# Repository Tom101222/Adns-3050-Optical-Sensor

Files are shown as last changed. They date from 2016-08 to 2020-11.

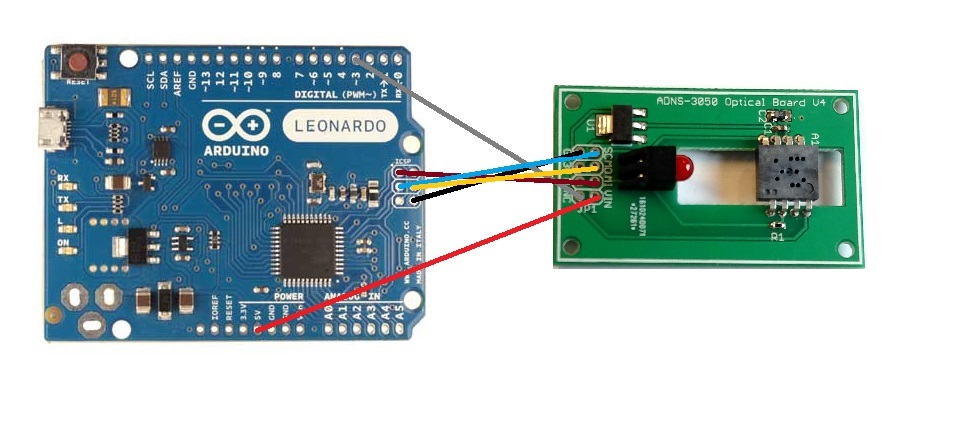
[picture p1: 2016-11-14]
Documentation/Wiring_Diagram.jpg

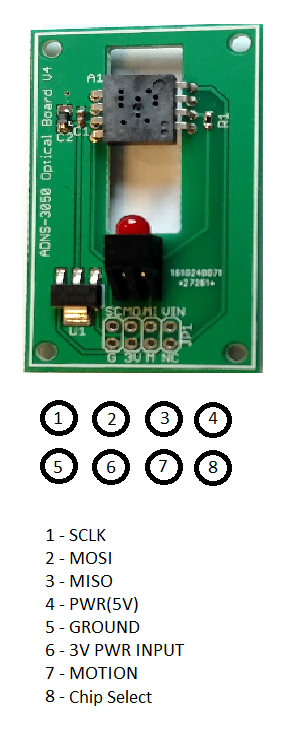
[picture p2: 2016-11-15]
Documentation/pinout.png

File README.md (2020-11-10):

# Adns-3050-Optical-Sensor
Library and Eagle cad files for the Adns-3050 Sensor

Boards are now avaible for purchase on tindie! https://www.tindie.com/products/tom10122/adns-3050-optical-sensor-board/

Overview

The ADNS 3050 is an entry level gaming sensor with up to 2000cpi resolution. It uses 6 wires to communicate via SPI(including Power) and can be used to create your own computer mouse in addition to other uses in robotics. 

Setup

Wiring
The pins used in the program are defined at the top of the header file.

MOSI -- MOSI, 

MISO -- MISO, 

SCLK -- SCLK, 

NCS -- 3 (any pin you want)

Software

A method has been provided to automate the setup of the sensor. It does not require as much setup as the adns-9800 laser based sensor. The default setup method (startup) uses all the default configuration options for the sensor but they can be changed easily. All configuration is done by writing to the correct registers on the sensor, a quick look over the datasheet should help anyone looking to change some settings, the write method can be used to write to the settings to the registers.  

Using to obtain postion

Once the startup method has been run it is easy to obtain the position of the sensor, just use getx() and gety() consecutively, it is important that there are no read operations between the two otherwise the data will be corrupted or changed.  

Sensor Operation

The ADNS 3050 is essentially a small camera. It takes consecutive photos and the DSP mathematically determines the amount of movement between pictures. The data is then stored in the DELTA_X and DELTA_Y registers (0X03 and 0X04 respectively) Once the the registers are read they are re-written with new data.

Setting the Resolution 

Resolution is determined by the value of bits 4-2 in the MOUSE_CNTRL register (0x0d). By default this is set to 1000 cpi. To change the resolution just write to the register with the corresponding value . For example, to set the resolution to 2000 cpi  just use:

Write(0x0d,B11000);

This sets bits 4-2 to 110 and bits 1 and 0 to 0 (needed for operation).  110 corresponds with the value found on page 29 of the datasheet for a resolution of 2000 

Lift off detection 

The sensor will stop tracking if the SQUAL is too low (usually when the sensor is too far off the ground). Sometimes when the sensor is placed back down it will not wake up. To mitigate/disable liftoff detection you can set the SQUAL_Threshold to 0 in the MISC_Settings register.The following code does just that:

Write(0x25,B0000001);

This should be run during setup.

Any questions or comments feel free to email me at twigg1012@gmail.com

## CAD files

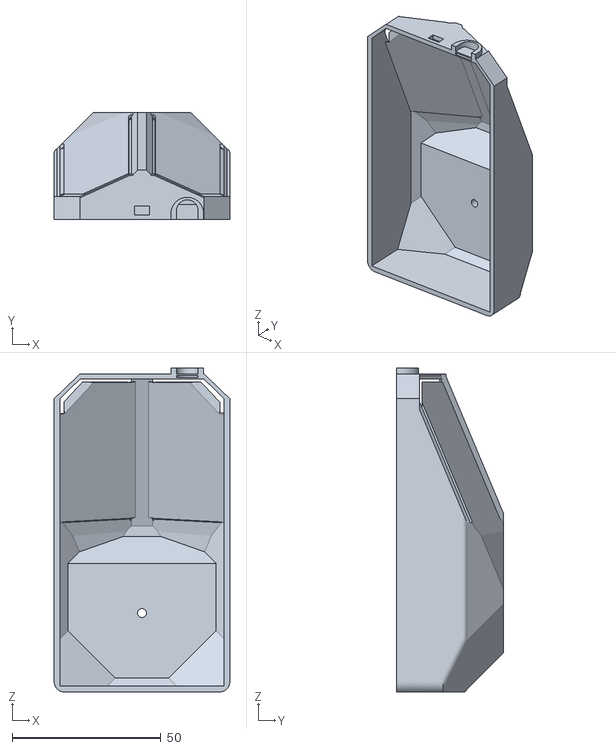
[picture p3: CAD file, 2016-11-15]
Hardware/3D Models/Mouse_Shell.stl
59.0 x 36.0 x 108.8

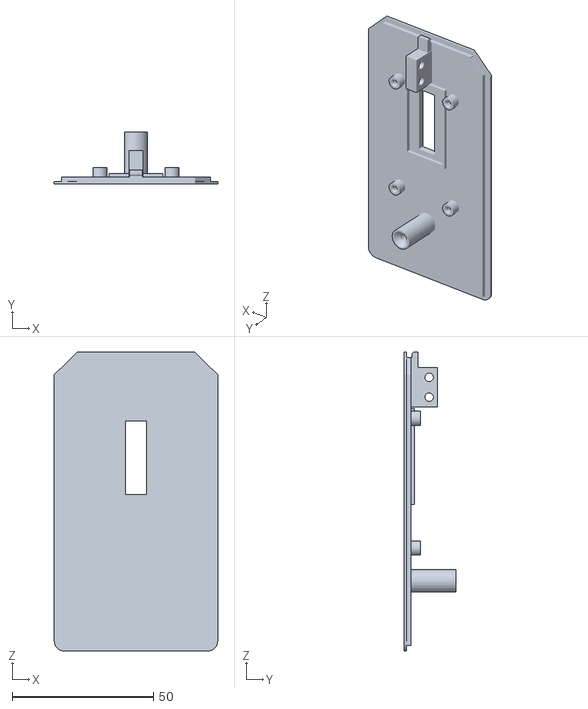
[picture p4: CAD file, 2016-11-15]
Hardware/3D Models/baseplate.stl
58.0 x 18.4 x 106.0

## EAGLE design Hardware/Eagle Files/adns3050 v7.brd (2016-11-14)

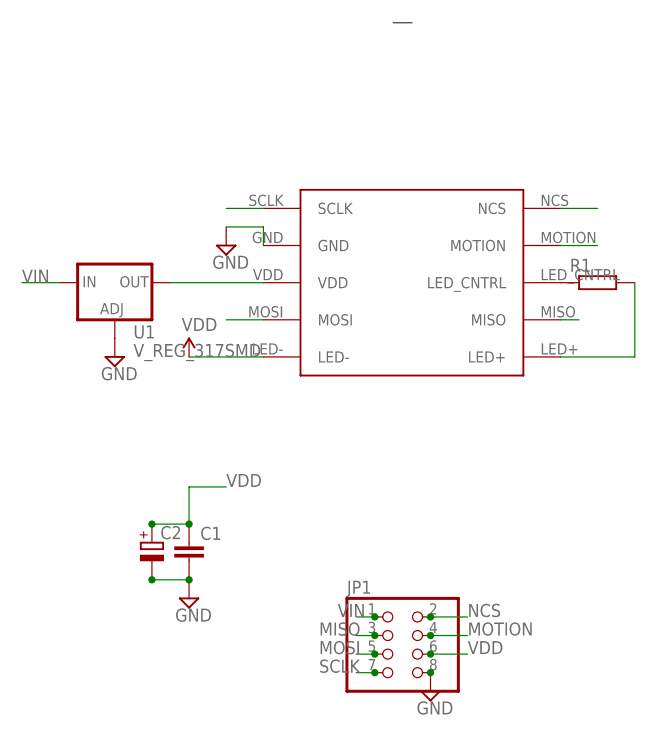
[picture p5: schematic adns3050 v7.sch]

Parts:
C1: CC0603; C0603
C2: CPOL-EUR/2012-12R; R/2012-12R
JP1: PINHD-2X4; 2X04
R1: RR0603; R0603
U1: V_REG_317SMD; SOT223
U$1: 3050; ADNS3

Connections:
GND: C1.2, C2.-, JP1.8, U1.1 (ADJ), U$1.GND
MISO: JP1.3, U$1.MISO
MOSI: JP1.5, U$1.MOSI
MOTION: JP1.4, U$1.MOTION
unnamed: R1.1, U$1.LED_CNTRL
unnamed: R1.2, U$1.LED+
NCS: JP1.2, U$1.NCS
SCLK: JP1.7, U$1.SCLK
VDD: C1.1, C2.+, JP1.6, U1.2 (OUT), U$1.LED-, U$1.VDD
VIN: JP1.1, U1.3 (IN)

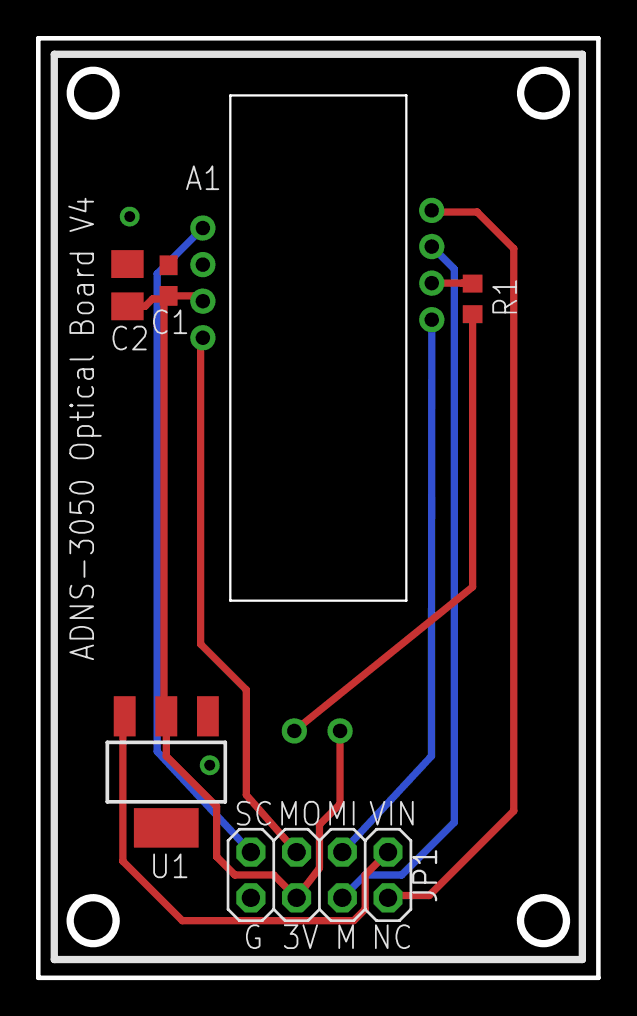
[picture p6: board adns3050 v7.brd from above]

Board: 2 copper layers, 31.1 x 52.2 mm, 6 parts (0 on the bottom side), 10 nets.

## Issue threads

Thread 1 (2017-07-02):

working with Teensy

robotpapier, 2017-07-02:
Hi,
is it working with Teensy 3.2?

Tom101222, 2017-07-02:
Hi, It will work with any device that can communicate over SPI, you just
need to change the pins used in the header file to match those on the
teensy ( MISO, MOSI, SCK, ECT)
Thanks.

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

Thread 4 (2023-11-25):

Low power (wireless) and rest mode

petanque, 2023-11-25:
Hi, thank you for sharing this.
I am trying to make a wireless version and it works with lower power but when I start rest mode I get no output on the serial port and it does not use less power as expected.

In your startup I added this:

//enable low power mode
Write(NAV_CTRL2, 0x00);
Write(FRAME_IDLE, 0x26);
Write(PREFLASH_RUN, 0x30);
Write(PREFLASH_RUN_DARK, 0x30);
Write(AUTO_LED_CONTROL, 0x01);
Write(LED_CTRL, 0x01);

//enable rest 1
Write(REST_MODE_CONFIG, 0x40);

Is this something you know something about and maybe have some advice?

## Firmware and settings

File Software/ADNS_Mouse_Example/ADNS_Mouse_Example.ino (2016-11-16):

#include "ADNS3050.h"
#include <SPI.h>
#include <Mouse.h>

byte x = 0;
byte y = 0;

void setup() {
startup();//setup communication

pinMode(8,INPUT_PULLUP);
pinMode(9,INPUT_PULLUP);
Mouse.begin(); //start mouse emulation

}


void loop() {
x = getX();
y = 0-getY();
Mouse.move(x,y,0);//Move the cursor

  if(digitalRead(9)==0){ //if the the left mouse button is pressed, press it
    Mouse.press(MOUSE_LEFT);
    while(digitalRead(9)==0){// while it is pressed move the cursor if the mouse is moved
      x = getX();
y = 0-getY();
  Mouse.move(x,y,0);
  delay(10);
    }
  }
   Mouse.release();//release the left mouse button
   
    if(digitalRead(8)==0){//if the the right mouse button is pressed, press it
    Mouse.press(MOUSE_RIGHT);
    while(digitalRead(8)==0){{// while it is pressed move the cursor if the mouse is moved
    x = getX();
    y = 0-getY();
  Mouse.move(x,y,0);
      delay(10);
    }
    }
  
Mouse.release(MOUSE_RIGHT);//release the right mouse button
}
}

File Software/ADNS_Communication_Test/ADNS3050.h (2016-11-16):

#include <SPI.h>

 // SPI and misc pins for the ADNS
 #define PIN_SCLK   SCK
 #define PIN_MISO   MISO
 #define PIN_MOSI   MOSI
 #define PIN_NCS    3
 #define PIN_MOTION 5


// Define all the registers
 #define PROD_ID                          0x00
 #define REV_ID                           0x01
 #define MOTION_ST                        0x02
 #define DELTA_X                          0x03
 #define DELTA_Y                          0x04
 #define SQUAL                            0x05
 #define SHUT_HI                          0x06
 #define SHUT_LO                          0x07
 #define PIX_MAX                          0x08
 #define PIX_ACCUM                        0x09
 #define PIX_MIN                          0x0a
 #define PIX_GRAB                         0x0b
 #define MOUSE_CTRL                       0x0d
 #define RUN_DOWNSHIFT                    0x0e
 #define REST1_PERIOD                     0x0f
 #define REST1_DOWNSHIFT                  0x10
 #define REST2_PERIOD                     0x11
 #define REST2_DOWNSHIFT                  0x12
 #define REST3_PERIOD                     0x13
 #define PREFLASH_RUN                     0x14
 #define PREFLASH_RUN_DARK                0x18
 #define MOTION_EXT                       0x1b
 #define SHUT_THR                         0x1c
 #define SQUAL_THRESHOLD                  0x1d
 #define NAV_CTRL2                        0x22
 #define MISC_SETTINGS                    0x25
 #define RESOLUTION                       0x33
 #define LED_PRECHARGE                    0x34
 #define FRAME_IDLE                       0x35
 #define RESET                            0x3a
 #define INV_REV_ID                       0x3f
 #define LED_CTRL                         0x40
 #define MOTION_CTRL                      0x41
 #define AUTO_LED_CONTROL                 0x43
 #define REST_MODE_CONFIG                 0x45


void com_start(){
  digitalWrite(PIN_NCS, HIGH);
  delay(20);
  digitalWrite(PIN_NCS, LOW);
}



byte Read(byte reg_addr){
  digitalWrite(PIN_NCS, LOW);//begin communication
  // send address of the register, with MSBit = 0 to say it's reading
  SPI.transfer(reg_addr & 0x7f );
  delayMicroseconds(100);
  // read data
  byte data = SPI.transfer(0);
  delayMicroseconds(30);
  digitalWrite(PIN_NCS, HIGH);//end communication
  delayMicroseconds(30);

  return data;
}


void Write(byte reg_addr, byte data){
  digitalWrite(PIN_NCS, LOW);
  //send address of the register, with MSBit = 1 to say it's writing
  SPI.transfer(reg_addr | 0x80 );
  //send data
  SPI.transfer(data);
  delayMicroseconds(30);
 digitalWrite(PIN_NCS, HIGH);//end communication
  delayMicroseconds(30);
}

void startup(){
  //--------Setup SPI Communication---------
  Serial.begin(115200);
  byte out = 0;
  byte read = 0;
  byte bit = 0;
  pinMode(PIN_MISO,INPUT);
  pinMode(PIN_NCS,OUTPUT);
  SPI.begin();
  // set the details of the communication
  SPI.setBitOrder(MSBFIRST); // transimission order of bits
  SPI.setDataMode(SPI_MODE3); // sampling on rising edge
  SPI.setClockDivider(SPI_CLOCK_DIV16); // 16MHz/16 = 1MHz
  delay(10);

  //----------------- Power Up and config ---------------
  com_start();
  Write(RESET, 0x5a); // force reset
  delay(100); // wait for it to reboot
  Write(MOUSE_CTRL, 0x20);//Setup Mouse Control
  Write(MOTION_CTRL, 0x00);//Clear Motion Control register
  delay(100);
  }



int convTwosComp(int b){ //Convert from 2's complement
   if(b & 0x80){
     b = -1 * ((b ^ 0xff) + 1);
     }
   return b;
   }

void getXY(){//Prints out X and Y values to the serial terminal, use getX and getY sequentially for most operations
  byte x = 0;
  byte y = 0;
	 x= Read(0x03);
	    y = Read(0x04);
     Serial.println("x");
	     Serial.println(convTwosComp(x));
      Serial.println("y");
Serial.println(convTwosComp(y));
}


int getX(){//returns the X acceleration value
  byte x = 0;
  x= Read(0x03);
  return(convTwosComp(x));
}

int getY(){//returns the Y acceleration value
  byte y = 0;
  y= Read(0x04);
  return(convTwosComp(y));
}

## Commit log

2016-08-23 Added Hardware and edited readme
    [adns3050 v6.brd, adns3050 v6.sch]
2016-08-23 Added Gerber Files
    [adns3050 v6.drills.xln]
2016-08-25 Added components
    [adns3050 v6.brd, adns3050 v6.sch]
2016-09-07 Updated board, increased text spacing
    [adns3050 v7.brd, adns3050 v7.sch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]
2016-11-14 Updated Gerbers + Documentation
    [adns3050 v7.brd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]
2016-11-15 Added Models
    [Mouse_Shell.stl, baseplate.stl]

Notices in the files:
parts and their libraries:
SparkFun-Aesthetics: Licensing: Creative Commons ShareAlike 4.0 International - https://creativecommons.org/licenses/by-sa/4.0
